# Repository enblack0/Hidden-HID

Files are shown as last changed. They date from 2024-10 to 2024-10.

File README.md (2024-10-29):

# Hidden-HID
Hidden HID is tiny USB device that can be concealed entirely inside a USB A port. 
Once inserted it is almost invisible to those unaware of its presence. 



It consists of a single 8x12x0.4mm PCB with USB contacts on the top layer and an STM32 on the bottom.
The additional height required to maintain contact with the USB pins is achieved with 3 1206 LEDs with height 1.8mm soldered to the pads on either side. These are not electrically connected.





Here you will find kicad design files. The firmware is a work in progress and not currently uploaded.

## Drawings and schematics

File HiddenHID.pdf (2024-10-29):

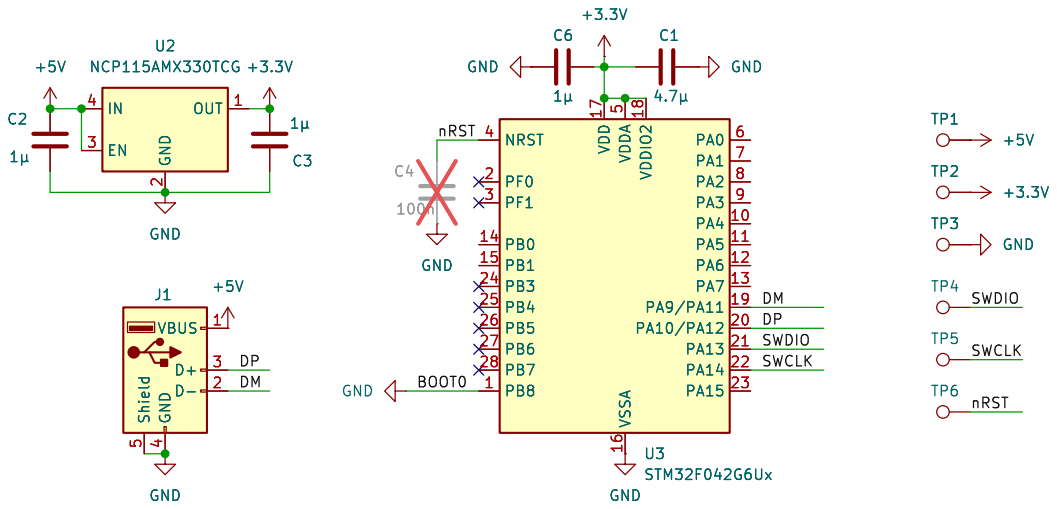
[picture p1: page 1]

Id: 1/1 Title: File: HiddenHID.kicad_sch Sheet: /

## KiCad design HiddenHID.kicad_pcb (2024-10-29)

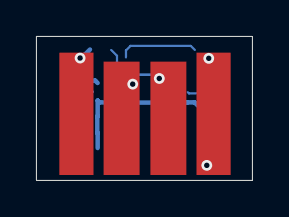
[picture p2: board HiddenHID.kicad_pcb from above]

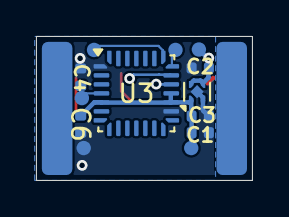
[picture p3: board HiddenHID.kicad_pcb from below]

Board: 2 copper layers, 12.0 x 8.0 mm, 14 parts (13 on the bottom side), 8 nets.

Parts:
C1: 4.7µ; C_0402_1005Metric_noSS
C2, C3, C6: 1µ; C_0402_1005Metric_noSS
C4: 100n; C_0402_1005Metric_noSS
J1: USB_A; usb-PCB
TP1, TP2, TP3, TP4, TP5, TP6: TestPoint_Pad_D0.8mm
U2: NCP115AMX330TCG; OnSemi_XDFN4-1EP_1.0x1.0mm_EP0.52x0.52mm
U3: STM32F042G6Ux; QFN-28_4x4mm_P0.5mm

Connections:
+3.3V: C1.2, C3.2, C6.1, TP2.1, U2.1 (OUT), U3.5 (VDDA), U3.17 (VDD), U3.18 (VDDIO2)
+5V: C2.1, J1.1 (VBUS), TP1.1, U2.3 (EN), U2.4 (IN)
/DM: J1.2 (D-), U3.19 (PA9/PA11)
/DP: J1.3 (D+), U3.20 (PA10/PA12)
/SWCLK: TP5.1, U3.22 (PA14)
/SWDIO: TP4.1, U3.21 (PA13)
/nRST: C4.1, TP6.1, U3.4 (NRST)
GND: C1.1, C2.2, C3.1, C4.2, C6.2, J1.4 (GND), TP3.1, U2.2 (GND), U2.5 (GND), U3.1 (PB8), U3.16 (VSSA)
